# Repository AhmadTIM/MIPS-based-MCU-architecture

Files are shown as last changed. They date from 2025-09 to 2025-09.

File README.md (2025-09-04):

# Pipelined MIPS Based MCU Architecture – VHDL Implementation

## Introduction
This repository features a 5-stage pipelined MIPS CPU implemented in VHDL, designed for the Altera DE10 FPGA platform. The system integrates core MIPS functionalities along with GPIO, a basic timer, FIR filter hardware accelerator, an interrupt controller, and UART communication, providing a complete microcontroller environment on the FPGA.  

## Contents
1. [Project Objective and System Overview](#project-objective-and-system-overview)  
2. [Verification and Testing](#verification-and-testing)  
3. [GPIO Module](#gpio-module)  
4. [Interrupt Handling](#interrupt-handling)  
5. [Basic Timer](#basic-timer)  
6. [FIR Filter HW-Accelerator](#fir-filter-hw-accelerator)  
7. [UART Interface](#uart-interface)  

## Project Objective and System Overview
The goal of this project was to implement a MIPS-based CPU capable of handling memory-mapped peripherals, processing external interrupts, and executing interrupt service routines (ISRs). Hazard detection and forwarding units resolve data dependencies, ensuring smooth pipelined operation on the FPGA.  

### System Architecture
The CPU consists of multiple interconnected modules working together in a pipelined configuration. Each module is encapsulated within the top-level microcontroller design, making the system modular and easier to debug.  

## Verification and Testing
Functional verification was performed using assembly programs covering arithmetic operations, memory access, and peripheral interactions. Simulations were conducted using ModelSim and FPGA-specific debugging tools to ensure correct CPU operation.  

## GPIO Module
The General-Purpose Input/Output (GPIO) module allows the CPU to interface with external devices such as LEDs and switches. It supports both input and output, enabling versatile hardware interaction.  

## Interrupt Handling
The interrupt controller manages external interrupts, prioritizes events, and triggers the appropriate ISRs. This ensures real-time responsiveness while maintaining smooth pipeline operation.  

## Basic Timer
The hardware timer module provides precise timing for the CPU. It supports periodic interrupts, PWM signal generation, and scheduling of recurring tasks.  

## FIR Filter HW-Accelerator
A dedicated module for fast digital filtering. It uses an 8-word FIFO and dual clocks to apply configurable coefficients to incoming data, producing filtered outputs for signal processing tasks.  

## UART Interface
The UART module enables serial communication between the CPU and external devices such as PCs or sensors, essential for debugging and real-time data exchange.  

## FPGA Configuration
Project files include pin assignments and constraints for proper operation on the Altera DE10 board, ensuring correct mapping of CPU signals and peripheral connections.  

## Project Components
The system is composed of several functional blocks:  

- **Top-Level Integration** – Connects all modules and manages overall CPU operation.  
- **CPU Core** – Implements the pipelined MIPS processor with fetch, decode, execute, memory access, and write-back stages.  
- **Control Unit** – Directs instruction flow and manages pipeline control.  
- **Data Hazard Management** – Detects and resolves dependencies using forwarding and hazard detection logic.  
- **Memory Interfaces** – Provide access to instruction and data memory.  
- **GPIO Interface** – Supports digital input/output operations with peripherals.  
- **Timer Module** – Provides precise timing for tasks and interrupts.  
- **FIR Filter Module** – Performs fast digital filtering.  
- **Interrupt Controller** – Handles external interrupts and ISR execution.  
- **UART Communication** – Enables serial data transfer.  
- **Utility Modules** – Support data conversion, peripheral interfacing, and general CPU functionality.  

## Supplementary Materials
- Simulation waveforms and logs demonstrating CPU operation  
- Test programs showcasing pipeline and peripheral functionality  

## Reference
For detailed explanations of module functionality and internal processes, consult the provided PDF:  
[MIPS-based-MCU-architecture.pdf](https://github.com/AhmadTIM/MIPS-based-MCU-architecture/blob/main/DOC/MIPS-based-MCU-architecture.pdf)

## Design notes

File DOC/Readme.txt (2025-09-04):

aux_package - package file that contains the components.

BasicTimer - contains the Basic Timer component which has a register counter, IFG and PWM output.

cond_comilation_package - contains constant values that differentiate between MODELSIM and QUARTUS.

const_package - contains constant values that equals to the corresponding Opcodes values of the instructions.

CONTROL - the unit that chooses which control signals to turn on.

DMEMORY - the unit that contains the data memory of the cpu.

EXECUTE - the unit that contains the ALU and the unit that chooses which operation that the ALU should preform.

FIR - contains the file for the FIR Filter HW accelerator component.

PulseSynch - is Pulse synchronizer between to clocks of different frequencies.

FarwardingUnit - This VHDL code implements a forwarding unit that detects and resolves data hazards in a pipelined MIPS processor by selecting the correct forwarding paths for ALU and branch operands from later pipeline stages.

GPIO - connects between the LEDs, HEXs and SWs and the MCU.

HazardUnit - This VHDL code defines a Hazard Detection Unit for a MIPS pipeline that detects load-use and branch hazards and asserts stall and flush signals to manage pipeline control.

IDecode - contains the register file, and calculates the jump and branch address to pass them to IFetch

IFetch - responsible to fetch the next instruction, whether it is PC+4 or instruction that was jumped (or branched) to.

Int_Cont - contains the code for the Interrupt Controller.

MCU - contains the overall system, which contains MIPS cpu, Interrupt Controller, GPIO, UART, Basic Timer and FIR.

MIPS - the top level system that connects all the units together.

PLL_sub - switches the 50MHz clock to a more suitable clock in MHZ.

PLL_FIR + Counter_Env - switches the 50MHz clock to a more suitable clock in KHZ for FIR.

SevenSegDecoder - translates the inputed number for printing on HEX ports.

UART_TX - contains the component which transmits data to the connected device.

UART_RX - contains the component which receives data from the connected device.

UART - connects between UART_TX and UART_RX.

WriteBack - this unit is responsible for writing back to the register file and chooses if the memory value or the ALU result to pass to the RF.

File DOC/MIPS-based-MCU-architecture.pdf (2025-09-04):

# ADVANCED CPU ARCHITECTURE AND HARDWARE ACCELERATORS LAB

# FINAL PROJECT

# MIPS BASED MCU ARCHITECTURE

361.1.4693

Table of Contents

### System Overview

This project focuses on designing an MCU featuring a 5-stage pipelined MIPS processor, comprising the stages WB, MEM, EX, ID, and IF. The processor includes a hazard detection unit to identify and manage potential execution conflicts.

In addition to the CPU, the system integrates several hardware peripherals that interact and operate together as needed. Communication between all components is handled via three shared bus lines, which transmit relevant data between sources and destinations.

Below is a block diagram representing the overall system architecture –

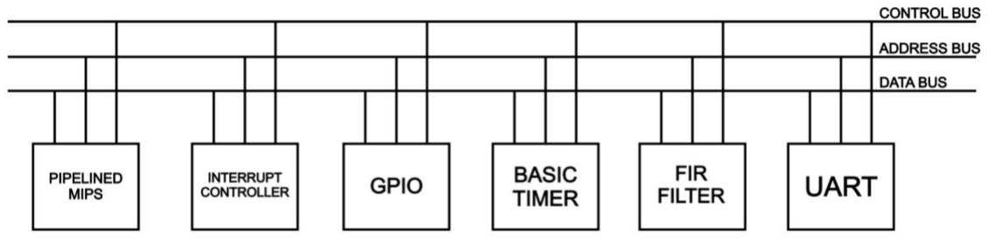
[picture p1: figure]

This section presents an overview of the RTL structure within this module:

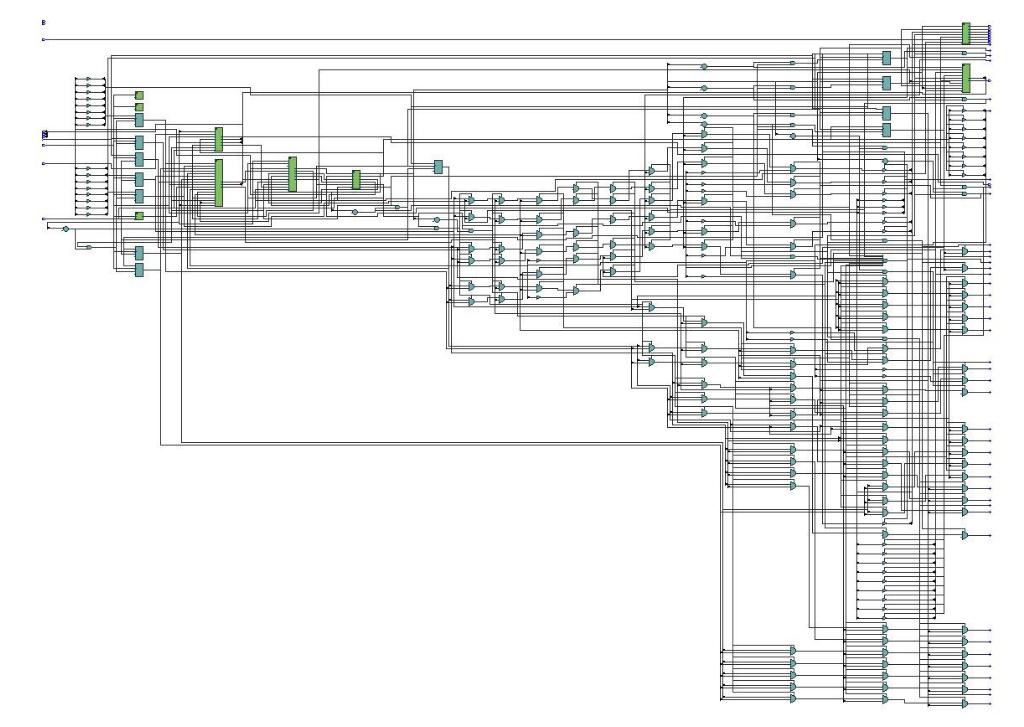
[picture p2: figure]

The module employs combinational logic as part of its internal operations:

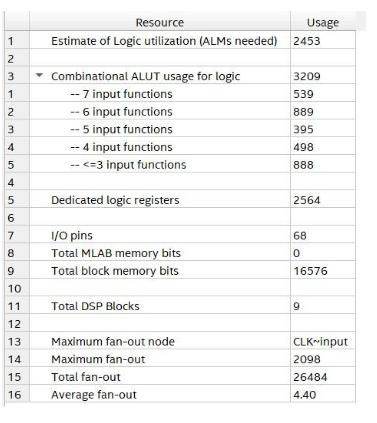
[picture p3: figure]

### MIPS

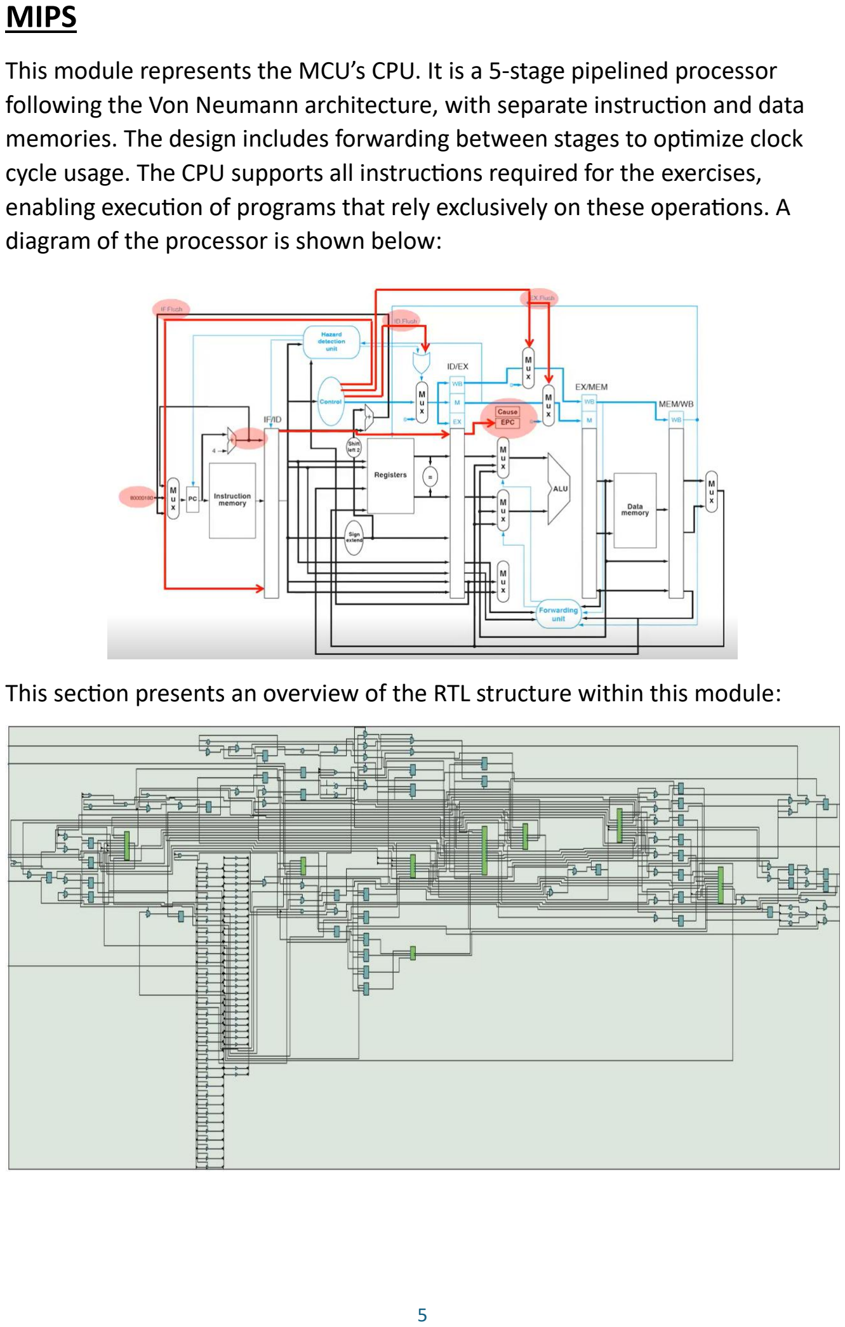
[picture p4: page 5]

This module represents the MCU’s CPU. It is a 5-stage pipelined processor following the Von Neumann architecture, with separate instruction and data memories. The design includes forwarding between stages to optimize clock cycle usage. The CPU supports all instructions required for the exercises, enabling execution of programs that rely exclusively on these operations. A diagram of the processor is shown below:

This section presents an overview of the RTL structure within this module:

Graphical representation of the module:

Instruction Fetch

This stage retrieves the instruction located at the current program counter (PC) from instruction memory. It also handles updating the PC, which can happen in several ways:

- Jumping to a specific target address.
- Branching to a calculated address.
- Moving to the next sequential instruction.

Instruction Decode

In this stage, the fetched instruction is analyzed according to its type. The instruction is broken down into its components using the instruction encoding, as shown below:

The required registers are identified and their values are read. Branch and jump decisions are also evaluated at this stage, since the necessary information is now available. Control logic interprets the instruction and generates the necessary signals for later stages.

Execute

In the execution stage, arithmetic, logic, or memory-related calculations are performed. This includes evaluating branch conditions and determining the next PC.

For pipelined processors, branches can create hazards because the next instruction may depend on the branch outcome. Solutions include stalling or predicting the branch result. In this design, branch decisions are moved earlier to reduce wasted cycles and improve efficiency.

Data forwarding is applied when needed to resolve dependencies between instructions.

Data Memory

This stage handles reading from and writing to the system’s main memory.

Write Back

The final stage returns results to the registers. Instructions that produce a result, whether from memory or computations, update the appropriate register to complete execution.

### Basic Timer

The BasicTimer module is a 32-bit timer peripheral that provides counting, PWM generation, and interrupt signaling. It increments a counter based on a selected internal clock, with configurable compare values to control PWM output. The timer supports clock division, counter reload, and overflow detection. An interrupt flag output indicates events such as compare matches or counter overflow, allowing external systems to respond to timer events.

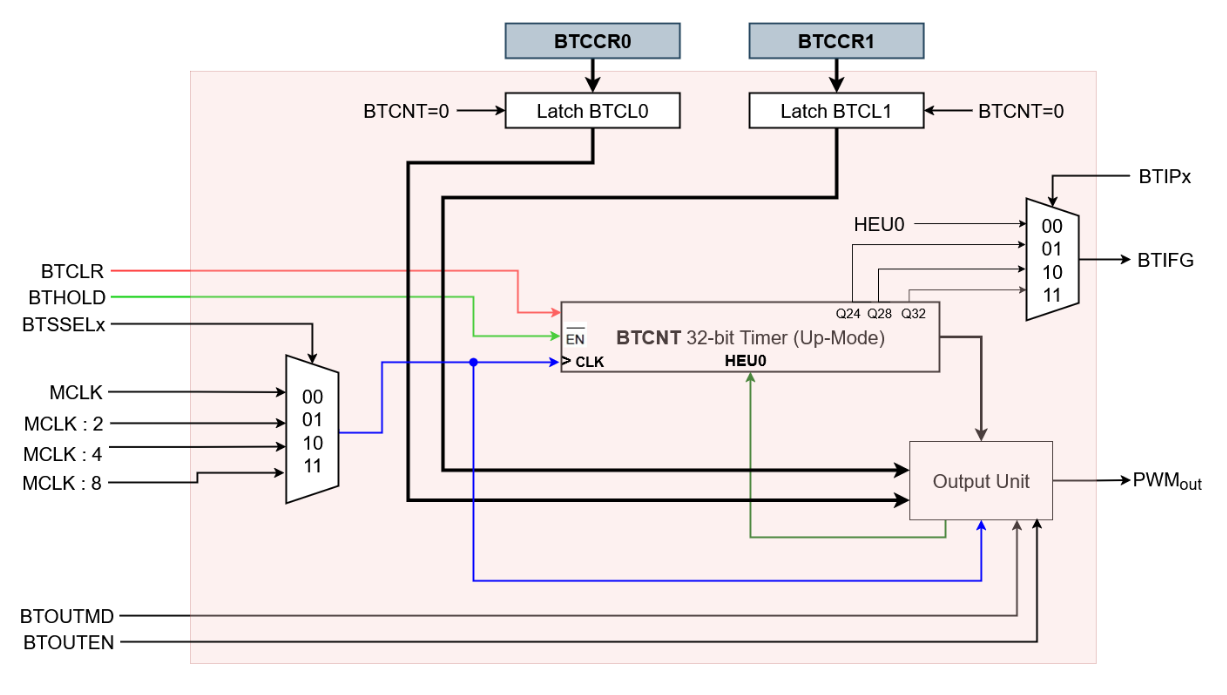
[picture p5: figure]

This section presents an overview of the RTL structure within this module:

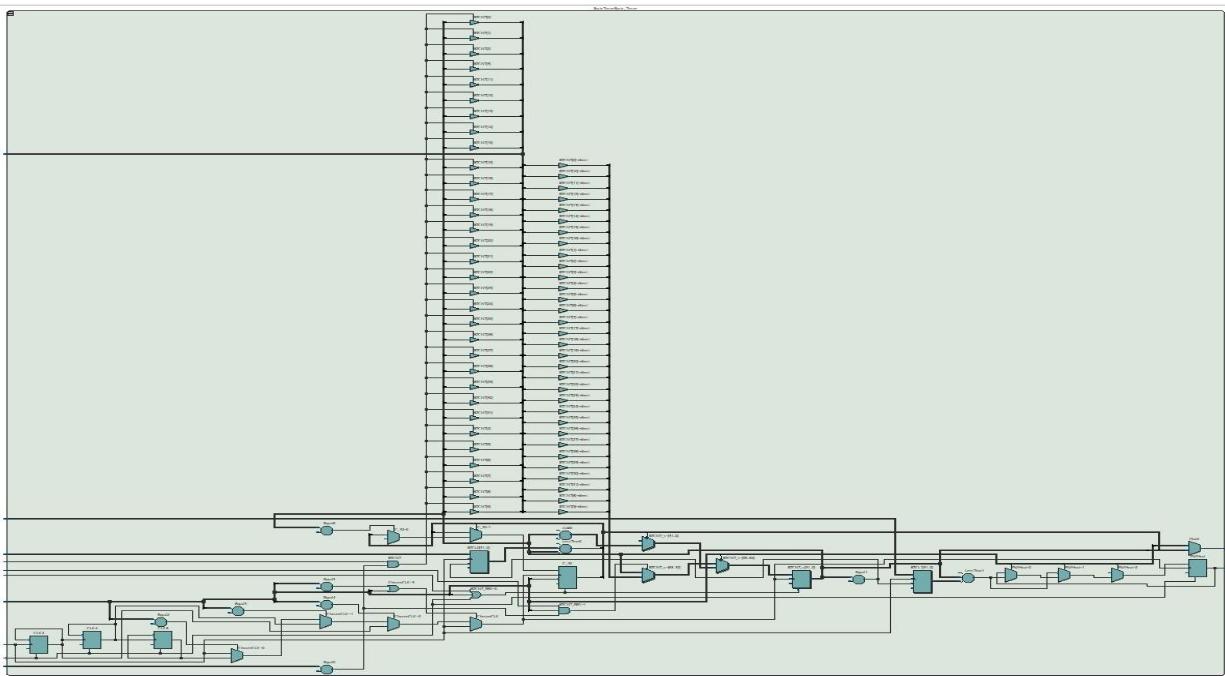
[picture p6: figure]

Graphical representation of the module:

### FIR filter HW-Accelerator

The module implements a FIR filter with an 8-word FIFO and dual-clock operation. FIFOCLK handles high-speed data writes, while FIRCLK processes filtering at a lower rate using eight configurable coefficients. The design multiplies current and previous input samples by the coefficients, sums the results, and outputs the filtered data. Status signals indicate FIFO full/empty conditions, and a pulse synchronizer ensures safe transfer of the enable signal between the two clock domains.

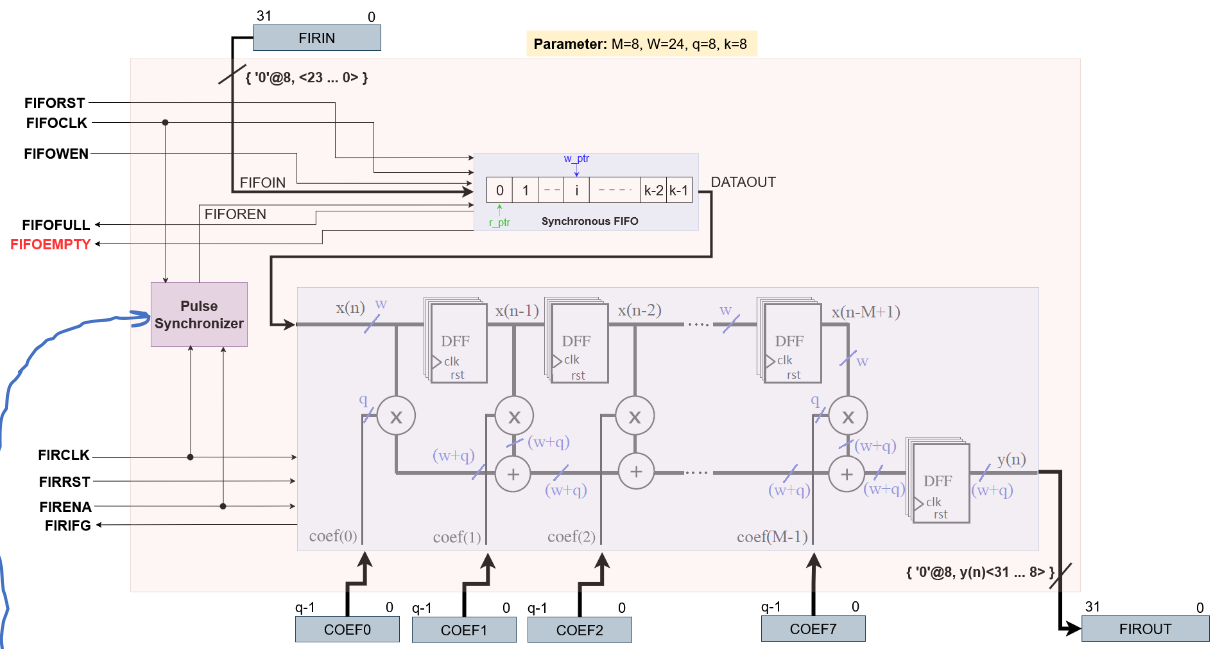
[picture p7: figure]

Pulse Synchronizer Diagram:

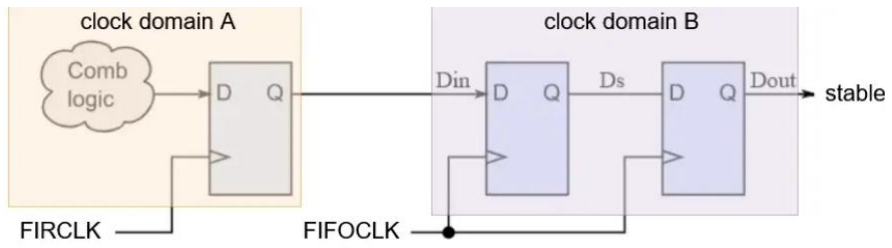
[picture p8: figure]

This section presents an overview of the RTL structure within this module:

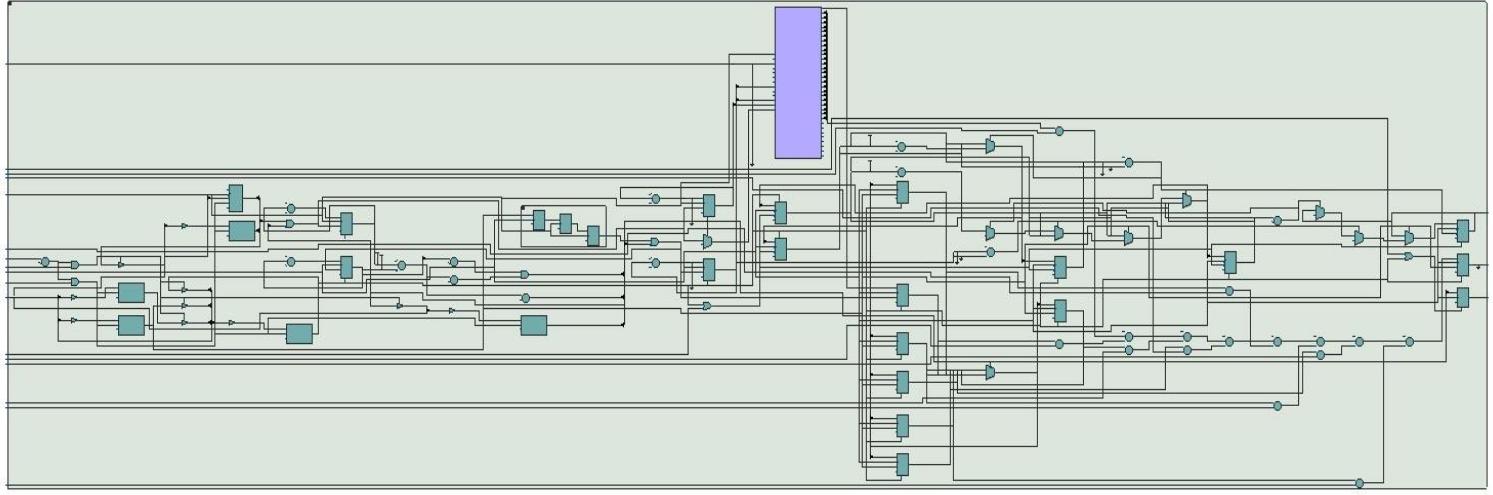
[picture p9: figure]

Graphical representation of the module:

### Interrupt Controller

The module implements an interrupt controller for a microcontroller. It monitors multiple interrupt sources, manages their status, and signals the CPU when an interrupt occurs. The controller tracks which interrupts are enabled, which are pending, and the type of active interrupt.

Special cases like UART errors and FIFO-empty conditions are handled separately. Each interrupt can be cleared when acknowledged by the CPU, and the module provides outputs for individual interrupt sources, active interrupt status, and the corresponding interrupt vector.

In summary, it centralizes interrupt handling, allowing the CPU to efficiently detect and respond to multiple hardware events.

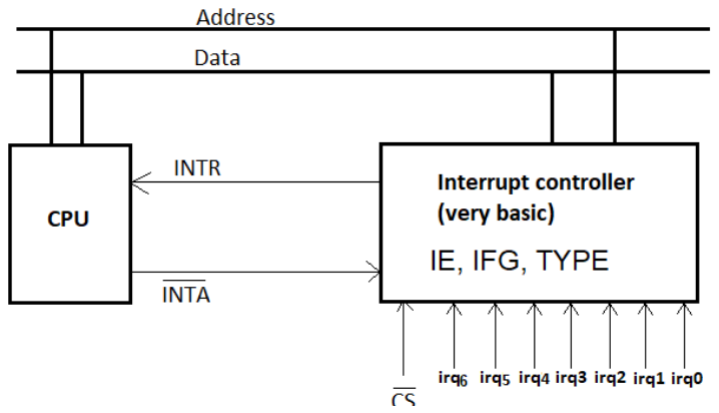
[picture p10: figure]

Interrupt Controller Design:

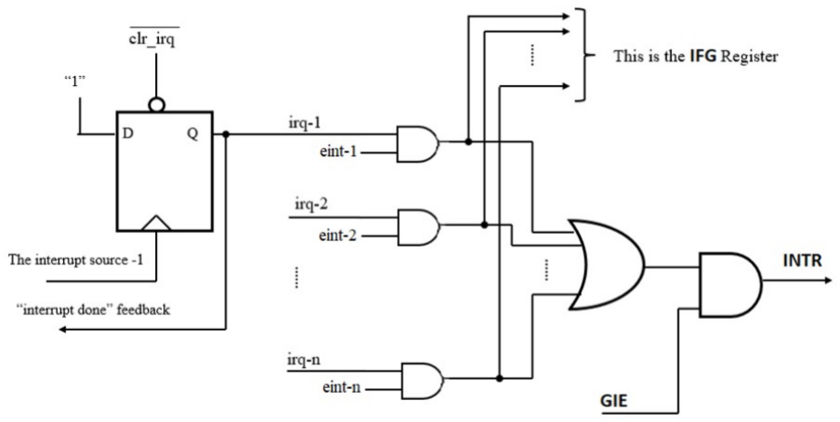
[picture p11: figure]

This section presents an overview of the RTL structure within this module:

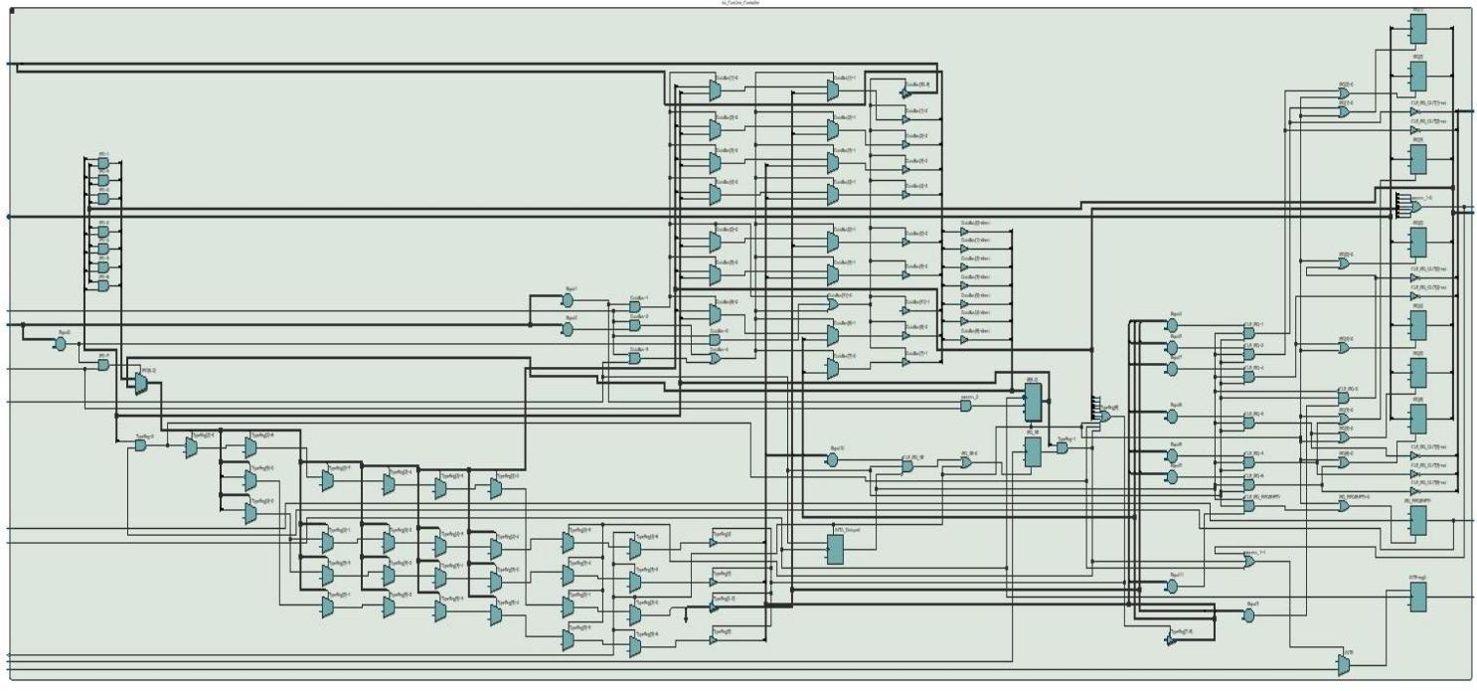
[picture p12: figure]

Graphical representation of the module:

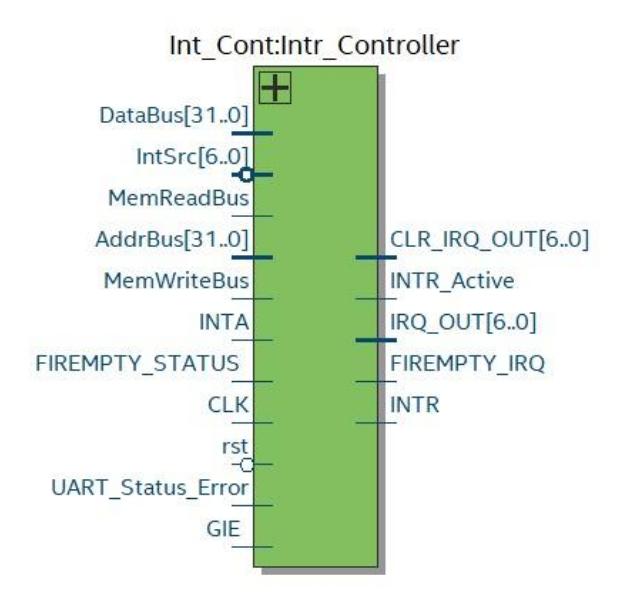
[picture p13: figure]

### UART

The UART module provides serial communication for a system. It supports data transmission and reception through memory-mapped registers, allows configuration via control settings, and reports status and errors such as framing, parity, and overrun.

It includes registers for control (UCTL), transmit data (TXBUF), and received data (RXBUF). The module uses a clock divider based on the system clock and baud rate to ensure correct timing for serial communication.

The module integrates separate receiver (UART_RX) and transmitter (UART_TX) components. The receiver captures incoming serial data and signals when valid data is available, while the transmitter sends data from the buffer and indicates when transmission is complete, also reflecting busy status.

This section presents an overview of the RTL structure within this module:

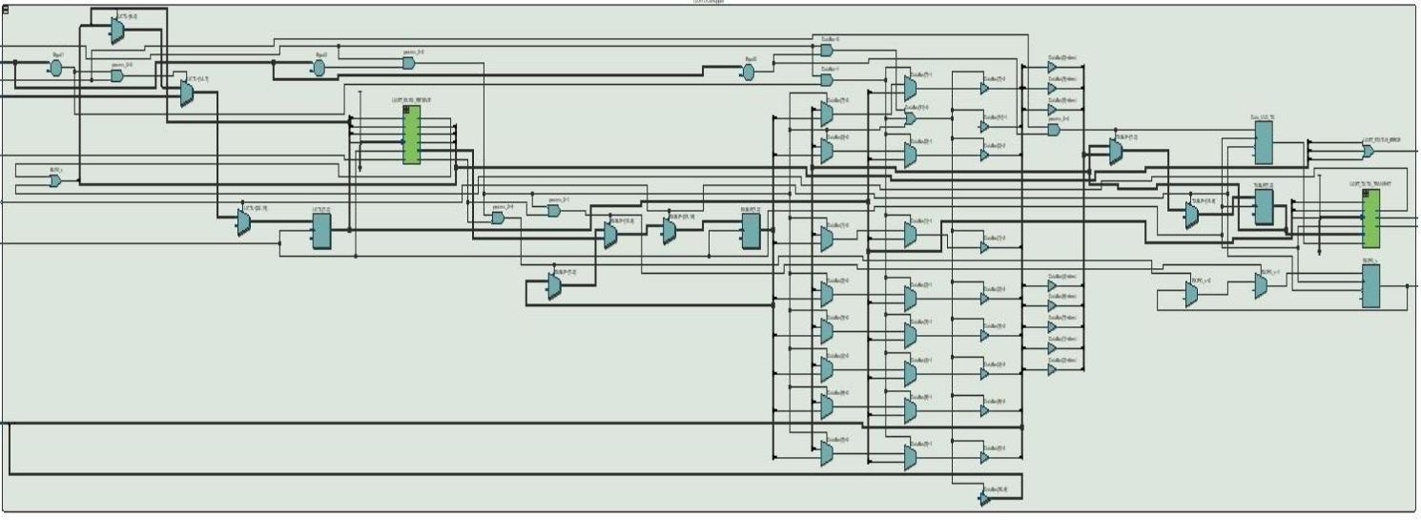
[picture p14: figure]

Graphical representation of the module:

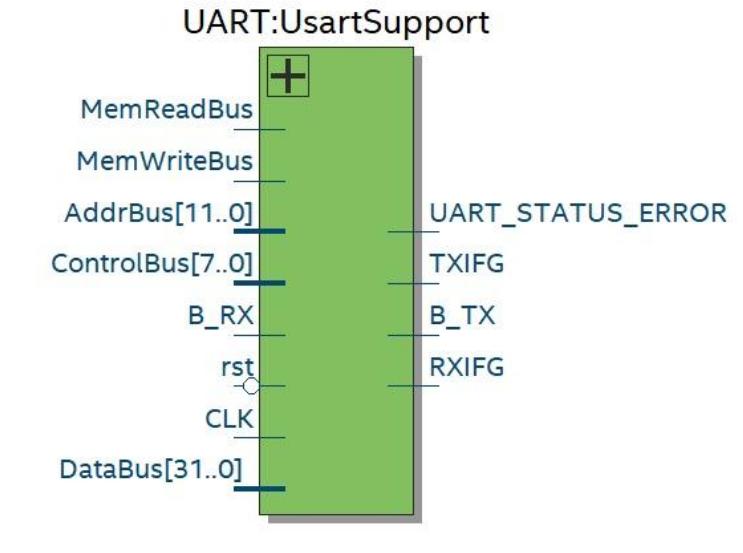
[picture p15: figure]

### GPIO

This GPIO module for an FPGA interfaces with switches, LEDs, and six 7-segment displays via a memory-mapped bus. It uses an address decoder to select peripherals and latches to store output values. On writes, the corresponding latch is updated, and on reads, the data from switches or stored outputs is placed on the data bus. The 7-segment outputs are driven through decoder modules, and the LEDs reflect the stored latch values.

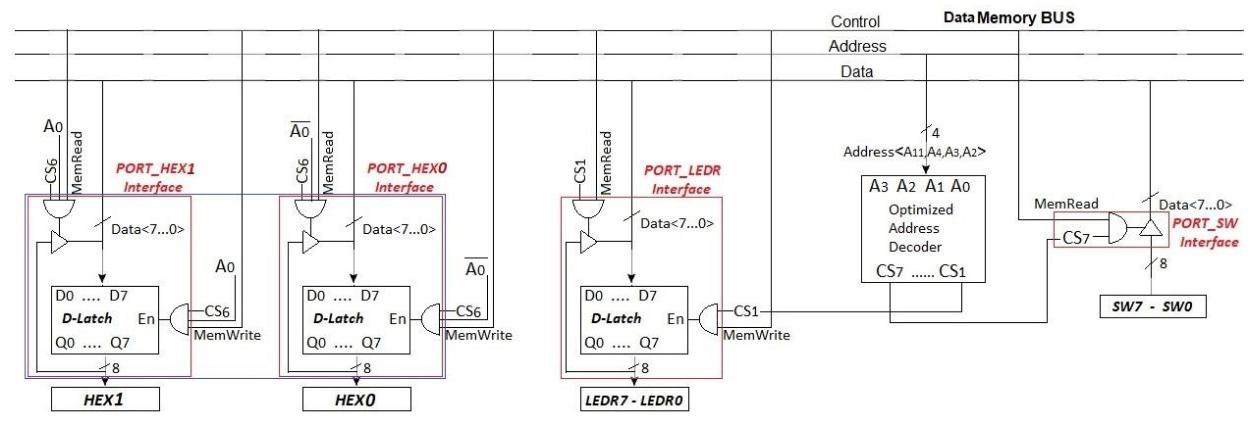
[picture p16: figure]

This section presents an overview of the RTL structure within this module:

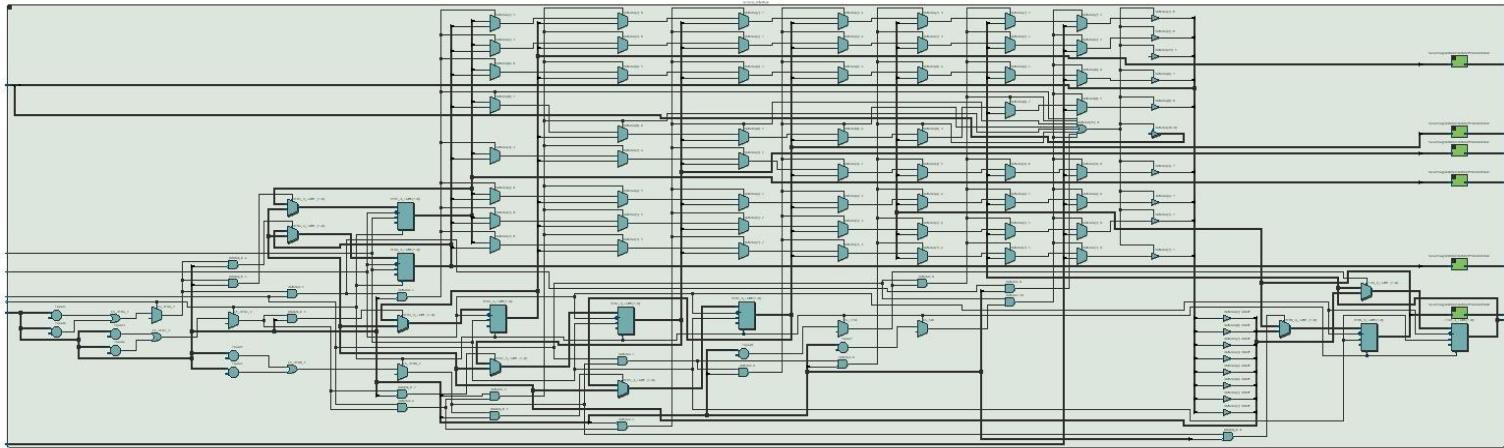
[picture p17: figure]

Graphical representation of the module:

### Critical Path

The critical path refers to the longest sequence of logic propagation within the digital circuit of the MCU design developed during this project. It determines the slowest part of the system, which in turn sets the maximum clock frequency that the MCU can safely operate at. The critical path in our system is as follows –

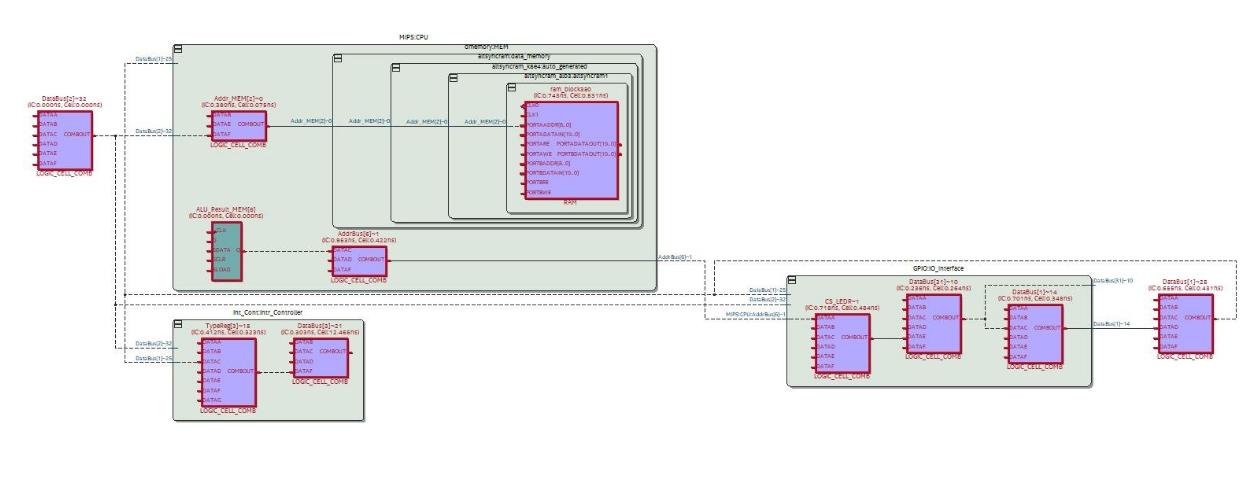
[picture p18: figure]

the process starts by placing the calculated address onto the address bus to select the target memory location. Next, the value of the Type register is computed and sent onto the data bus. This value then travels along the critical path to the data memory, enabling the intended read or write operation. By properly sequencing address calculation, Type register evaluation, and data transfer, the MCU ensures correct timing and maintains data integrity throughout memory access.
The maximum frequency of the MCU that is cause by the critical path is:

### Results Analysis

This section evaluates the performance of the implemented system and presents an analysis of the obtained results. The assessment focuses on two main areas:

1. Timing Evaluation – Examining critical delays and determining the feasible operating frequencies of the system.
2. Simulation Testing – Recording and inspecting signal waveforms using the FPGA’s Signal Tap tool to verify correct functionality and ensure compliance with design specifications.

ModelSIM Wave Analysis:

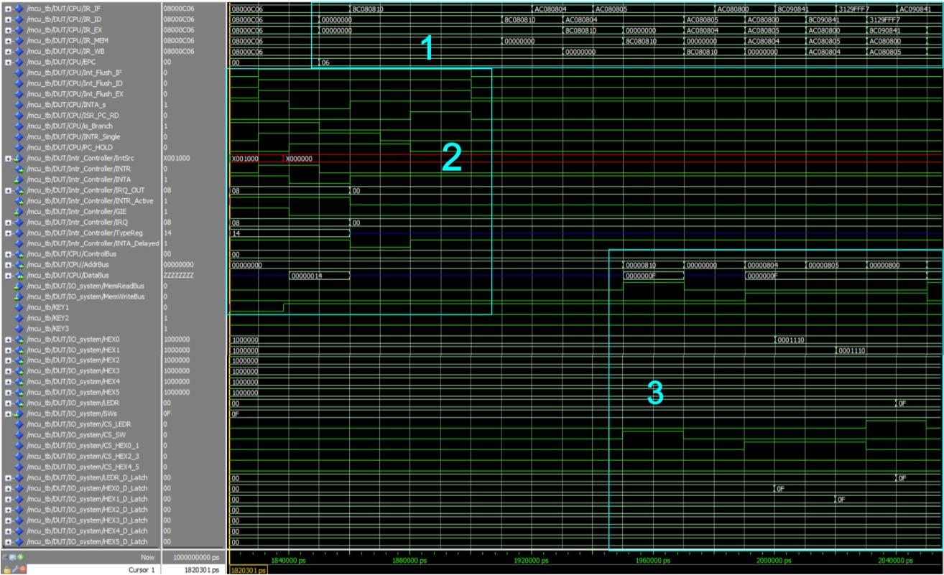
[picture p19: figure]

1. Interrupt Handling and Control Flow: In Circle 1, the controller interrupts its execution in the main infinite loop upon detection of a Button 1 (KEY1) press, immediately transferring control to the corresponding interrupt service routine (ISR). This demonstrates proper prioritization of asynchronous events. After the ISR completes, the system resumes execution in the main loop without loss of state, indicating effective context preservation and seamless interrupt management.

2. CPU Interrupt Signaling: In Circle 2, the CPU receives the interrupt request (INTR) triggered by the button press. The subsequent acknowledgment via the INTA signal confirms that the CPU correctly recognizes and processes the interrupt. This sequence validates the interrupt handshake mechanism, ensuring that signal timing and CPU response align with expected hardware behavior.
3. GPIO Data Capture and Output Verification: In Circle 3, the GPIO module accurately captures input data and presents it on the LEDs. Observed register states correspond precisely to the expected values, confirming correct latching and data propagation. This also indicates reliable coordination between the interrupt-driven ISR and the GPIO output, demonstrating that the system maintains data integrity even during asynchronous events.

Signal Tab Analysis:

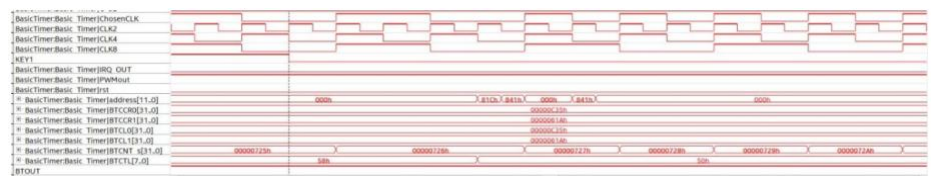
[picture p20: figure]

When KEY 1 is pressed, the system selects the CLK/4 clock as the timer’s source. As a result, the timer begins counting based on this divided clock frequency. This demonstrates how the first key can slow down the timer relative to the main clock, allowing for longer timing intervals or more controlled operations.

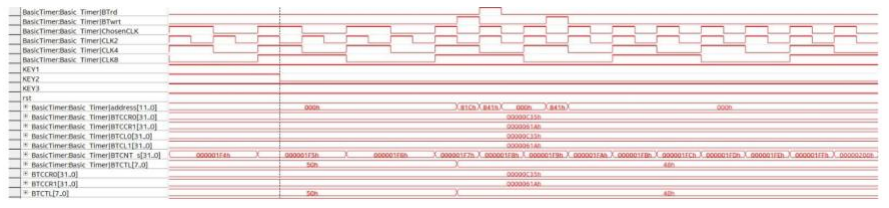
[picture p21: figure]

Pressing KEY 2 switches the timer to use the CLK/2 clock. The timer then runs at a faster rate than CLK/4 but still slower than the main clock. This illustrates the intermediate timing option provided by the second key, showing that the timer’s behavior can be adjusted dynamically based on the selected clock division.

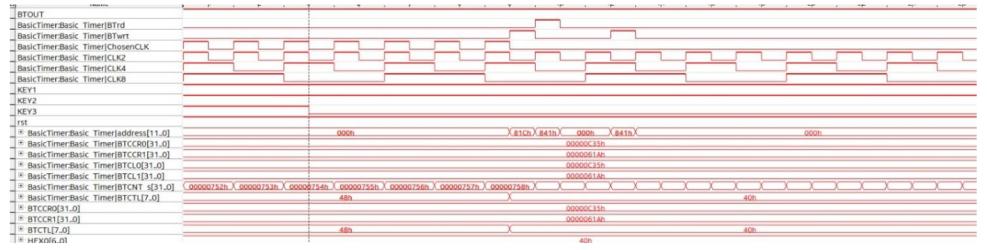
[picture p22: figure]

When KEY 3 is pressed, the timer uses the main clock without any division. Consequently, the timer operates at full speed. This confirms that all three keys correctly select the expected clock sources, allowing the system to operate at different rates depending on the chosen input.

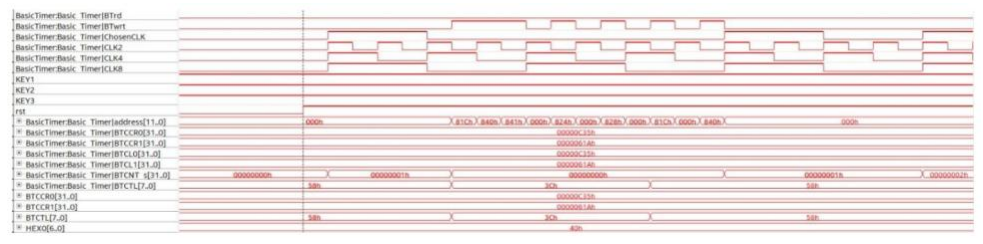
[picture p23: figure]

Pressing rst resets the clock selection back to CLK/8, returning the timer to a default slower rate. This demonstrates the reset functionality of the system, ensuring it can always return to a known starting configuration after user interaction or an event.

The PWM signal increases when the counter reaches the value of BTCL1. This shows how the timer output can be used to generate precise pulse-width modulation, linking the timer’s state to real output signals for control or signaling purposes.

After an interrupt occurs, the value of the LED port increments by 1. This shows the system’s response to asynchronous events, where the interrupt triggers a predictable change in output, illustrating the integration of timing and event-driven control.

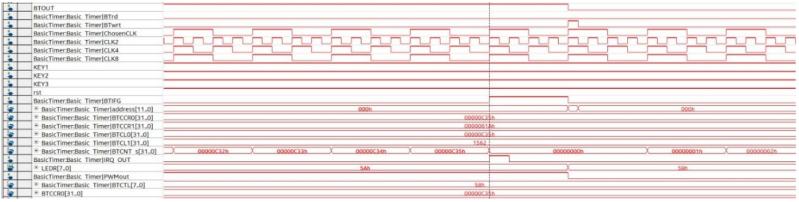
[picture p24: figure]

The system state after the interrupt is clearly observable, confirming that the LED port value has been updated correctly. This provides a visual verification that the interrupt mechanism and subsequent updates function as designed.

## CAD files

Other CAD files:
QUARTUS/MCU_STP.stp

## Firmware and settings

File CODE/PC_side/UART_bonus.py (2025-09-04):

import time
import serial as ser

# ---------------- UART Setup ----------------
def init_uart():
    global s
    s = ser.Serial('COM3', baudrate=115200, bytesize=ser.EIGHTBITS,
                   parity=ser.PARITY_NONE, stopbits=ser.STOPBITS_ONE,
                   timeout=1)
    s.reset_input_buffer()
    s.reset_output_buffer()


def Transmit_Char(char):
    global s
    s.write(bytes(char, 'ascii'))
    time.sleep(0.05)


def Recieve_Msg():
    chr = b''
    while chr[-1:] != b'\n':
        chr += s.read(1)
        if chr == b'':
            break
    return chr.decode('ascii')


# ---------------- Menu ----------------
def show_menu():
    print("\n================ MENU ================\n")
    print("1. Count up from 0x00 onto LEDG with delay ~0.5sec")
    print("2. Count down from 0xFF onto LEDR with delay ~0.5sec")
    print("3. Clear all LEDs")
    print('4. On each KEY1 pressed, send the message "I love my Negev"')
    print("5. Show Menu\n")


def main():
    init_uart()
    show_menu()

    while True:
        choice = input("Enter your choice: ").strip().upper()

        if choice == '1':
            Transmit_Char('2')
            print("Counting up from 0x00 onto LEDs...")
        elif choice == '2':
            Transmit_Char('3')
            print("Counting down from 0xFF onto LEDs...")
        elif choice == '3':
            Transmit_Char('1')
            print("Cleared all LEDs")
        elif choice == '4':
            Transmit_Char('4')
            print('Waiting for KEY1 presses to send...')
            try:
                while True:
                    msg = Recieve_Msg()
                    if msg:
                        print(msg, end='')
                    # allow exit by user input
                    if input("Press Enter to continue sending, type X to stop: ").strip().upper() == 'X':
                        break
            except KeyboardInterrupt:
                print("\nStopped listening for KEY1.")
        elif choice == '5':
            show_menu()
        else:
            print("Invalid choice! Try again.")


if __name__ == "__main__":
    main()

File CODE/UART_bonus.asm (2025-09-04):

#--------------------------------------------------------------
#		    		MEMORY Mapped I/O addresses
#--------------------------------------------------------------
#define PORT_LEDR[7-0] 	0x800 - LSB byte address (Output Mode)
.eqv PORT_LEDR 0x800     # Define a constant named PORT_LEDR
#------------------- PORT_HEX0_HEX1 ---------------------------
#define PORT_HEX0[7-0] 	0x804 - LSB byte address (Output Mode)
#define PORT_HEX1[7-0] 	0x805 - LSB byte address (Output Mode)
.eqv PORT_HEX0 0x804     # Define a constant named PORT_HEX0
.eqv PORT_HEX1 0x805     # Define a constant named PORT_HEX1
#------------------- PORT_HEX2_HEX3 ---------------------------
#define PORT_HEX2[7-0] 	0x808 - LSB byte address (Output Mode)
#define PORT_HEX3[7-0] 	0x809 - LSB byte address (Output Mode)
.eqv PORT_HEX2 0x808     	# Define a constant named PORT_HEX2
.eqv PORT_HEX3 0x809     	# Define a constant named PORT_HEX3
#------------------- PORT_HEX4_HEX5 ---------------------------
#define PORT_HEX4[7-0] 	0x80C - LSB byte address (Output Mode)
#define PORT_HEX5[7-0] 	0x80D - LSB byte address (Output Mode)
.eqv PORT_HEX4 0x80C		# Define a constant named PORT_HEX4
.eqv PORT_HEX5 0x80D     	# Define a constant named PORT_HEX5
#--------------------------------------------------------------
#define PORT_SW[7-0] 	0x810 - LSB byte address (Input Mode)
.eqv PORT_SW 0x810			# Define a constant named PORT_SW
#--------------------------------------------------------------
#define PORT_KEY[3-1]  	0x814 - LSB nibble address (3 push-buttons - Input Mode)
.eqv PORT_KEY 0x814			# Define a constant named PORT_KEY
#--------------------------------------------------------------
#define UTCL           	0x818 - Byte address 
#define RXBF           	0x819 - Byte address 
#define TXBF           	0x81A - Byte address 
.eqv UTCL 0x818			# Define a constant named UTCL
.eqv RXBF 0x819			# Define a constant named RXBF
.eqv TXBF 0x81A			# Define a constant named TXBF
#--------------------------------------------------------------
#define BTCTL          	0x81C - LSB byte address 
#define BTCNT          	0x820 - Word address 
#define BTCCR0         	0x824 - Word address 
#define BTCCR1         	0x828 - Word address 
.eqv BTCTL 0x81C			# Define a constant named BTCTL
.eqv BTCNT 0x820			# Define a constant named BTCNT
.eqv BTCCR0 0x824			# Define a constant named BTCCR0
.eqv BTCCR1 0x828			# Define a constant named BTCCR1
#--------------------------------------------------------------
#define FIRCTL       	0x82C - Word address 
#define FIRIN        	0x830 - Word address 
#define FIROUT       	0x834 - Word address 
#define COEF3_0      	0x838 - Word address 
#define COEF7_4      	0x83C - Word address 
.eqv FIRCTL 0x82C			# Define a constant named FIRCTL
.eqv FIRIN 0x830			# Define a constant named FIRIN
.eqv FIROUT 0x834			# Define a constant named FIROUT
.eqv COEF3_0 0x838			# Define a constant named COEF3_0
.eqv COEF7_4 0x83C			# Define a constant named COEF7_4
#--------------------------------------------------------------
#define IE             	0x840 - LSB byte address 
#define IFG            	0x841 - LSB byte address 
#define TYPE           	0x842 - LSB byte address 
.eqv IE 0x840			# Define a constant named IE
.eqv IFG 0x841			# Define a constant named IFG
.eqv TYPE 0x842			# Define a constant named TYPE
#---------------------- Data Segment --------------------------
.data 
	IV: 	.word main            # Start of Interrupt Vector Table
		.word UartRX_ISR
		.word UartRX_ISR
		.word UartTX_ISR
	        .word BT_ISR
		.word KEY1_ISR
		.word KEY2_ISR
		.word KEY3_ISR
		.word FIR_ISR
		.word FIR_ISR
		
	msg:	.word 0x49 0x20 0x6C 0x6F 0x76 0x65 0x20 0x6D 0x79 0x20 0x4E 0x65 0x67 0x65 0x76 0x0A
	#  	      'I'       'l'  'o'  'v'  'e'       'm'  'y'       'N'  'e'  'g'  'e'  'v' '\n'		
#---------------------- Code Segment --------------------------	
.text
main:	addi $sp,$0,0x800 # $sp=0x800
	addi $s0,$0,0     # clear option 4 pressed flag
	addi $s1,$0, 0    # counting up/down flag
	
	addi $t5, $0, 0
	addi $t6, $0, 0
	addi $t7, $0, 0
	
	addi $t0,$0,0x21  
	sw   $t0,BTCTL    # BTCTL=0x26(BTIP=6, BTSSEL=0, BTHOLD=1)
	sw   $zero,BTCNT  # BTCNT=0
	addi $t0,$0,0x3B   
	sw   $t0,IE       # IE=0x3B (BTIE is disabled, all others enabled)
	sw   $zero,IFG    # IFG=0
	addi $t0,$0,0x09  
	sw   $t0,BTCTL    #  BTCTL=0x0E (BTIP=6, BTSSEL=1, BTHOLD=0 - 50MHz/2^25)
	addi $t0,$0,0x09
	sw   $t0,UTCL     # UTCL=0x09 (SWRST=1,115200 BR)
	addi $t0,$0,0x08
	sw   $t0,UTCL     # UTCL=0x08 (SWRST=0,115200 BR)
	ori  $k0,$k0,0x01 # EINT, $k0[0]=1 uses as GIE

L:	j    L		    # infinite loop

ClrLEDs: 	# get '1' from PC
	addi $t0,$0,0x3B  	# BTIE is disabled
	sw   $t0,IE       
	sw   $0, PORT_LEDR
	jr   $k1
	
CntUp:	 # get '2' from PC
	addi $t2, $0, 0		# init timer
	addi $s1, $0, 0		# 0 when count up (1 when down)
	addi $t0,$0,0x3F  	# BTIE is enabled
	sw   $t0,IE
	jr   $k1
	
CntDown:	# get '3' from PC
	addi $t2, $0, 0xFF	# init timer
	addi $s1, $0, 1		# 1 when count down (0 when up)
	addi $t0,$0,0x3F  	# BTIE is enabled
	sw   $t0,IE 
	jr   $k1

Transmit_Msg:	# get '4' from PC
	addi $t0,$0,0x3B  	# BTIE is disabled
	sw   $t0,IE
	addi $s0, $0, 1		# 1 when send msg (0 when inside funcs)	
	jr   $k1

KEY1_ISR: 
	lw   $t0,IFG # read IFG
	andi $t0,$t0,0xFFF7 
	sw   $t0,IFG # clr KEY1IFG
	beq  $s0, $0, Exit_ISR
	addi $t3,$0,0  		# index = 0
	la   $t4, msg		# get pointer
	lw   $t0, 0($t4)	
	sw   $t0,TXBF 		# write to trig TxIntr
Exit_ISR:
	jr   $k1
	
KEY2_ISR:
	lw   $t0,IFG # read IFG
	andi $t0,$t0,0xFFEF 
	sw   $t0,IFG # clr KEY1IFG
	jr   $k1

KEY3_ISR:
	lw   $t0,IFG # read IFG
	andi $t0,$t0,0xFFDF 
	sw   $t0,IFG # clr KEY1IFG
	jr   $k1

BT_ISR:
	bne  $s1, $0, BT_down
	addi $t2, $t2, 1
	j    SetLEDs
BT_down:addi $t2, $t2, -1
SetLEDs:sw   $t2,PORT_LEDR
	jr   $k1

FIR_ISR:	
	jr   $k1

UartRX_ISR:
	addi $s0, $0, 0
	lw   $t0, RXBF
	addi $t1, $0, 0x31
	beq  $t0, $t1, ClrLEDs
	addi $t1, $0, 0x32
	beq  $t0, $t1, CntUp
	addi $t1, $0, 0x33
	beq  $t0, $t1, CntDown
	addi $t1, $0, 0x34
	beq  $t0, $t1, Transmit_Msg
	jr   $k1

UartTX_ISR:
	addi $t3, $t3, 1
	addi $t4, $t4, 4
	slti $t0, $t3, 16
	beq  $t0, $0, Exit_ISR2
	lw   $t0, 0($t4)
	sw   $t0, TXBF
Exit_ISR2:
	jr   $k1
